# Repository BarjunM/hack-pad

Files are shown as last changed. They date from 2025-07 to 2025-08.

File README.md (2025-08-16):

# The DM’s Grimoire

The **DM’s Grimoire** is a D&D **macropad** built for Dungeon Masters to control their campaigns. With 9 mechanical keys, an OLED display, RGB lighting, and a custom spellbook‑style enclosure, this device becomes a physical “grimoire” of power for any tabletop roleplaying game.

---

## Why I Made This

As a long‑time Dungeon enjoyer and the permanent dungeon master (no thanks to my friends), I wanted something that was extremely functional — I wanted it to feel like an artifact from the game world itself. Instead of clicking around with a mouse, now I press a button and summon a thunderstorm… or a dragon roar.

---

## Project Photos

### Front View  
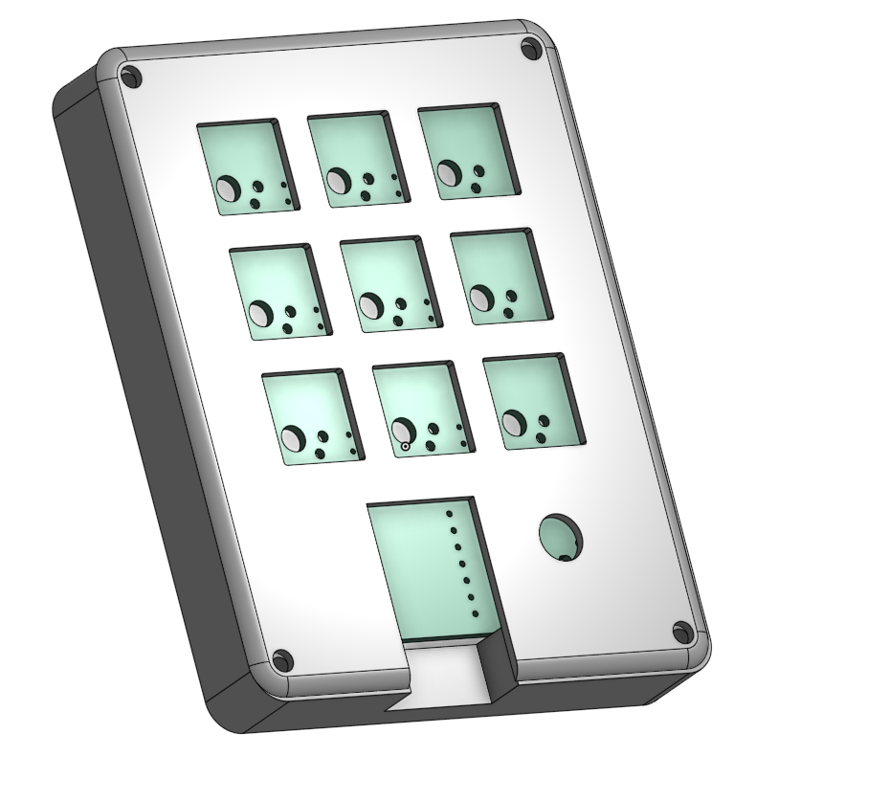
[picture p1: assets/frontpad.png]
Front of macropad


### Back View  
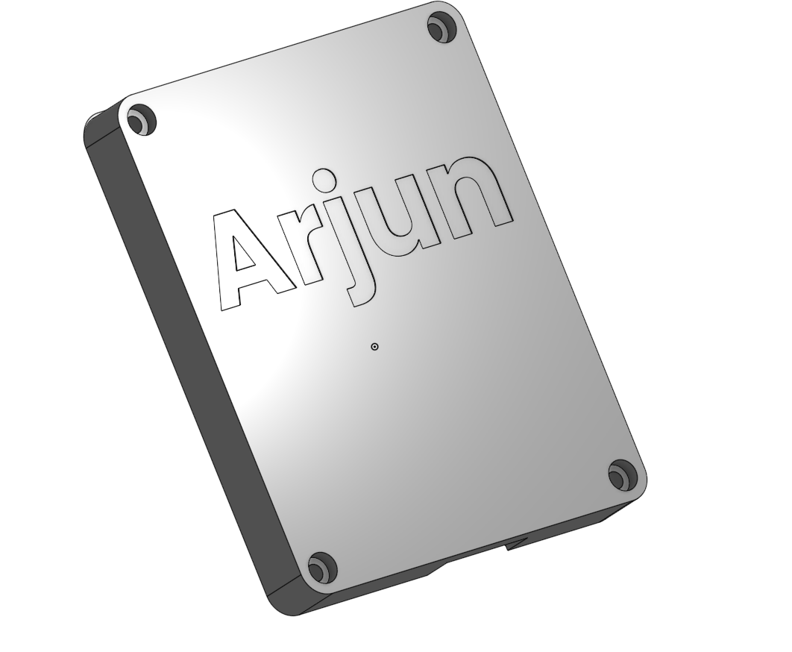
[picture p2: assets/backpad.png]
Back of macropad


---

## Key Orientation Screenshot

The 3D‑printed case was modeled in Onshape for a 3x3 matrix.

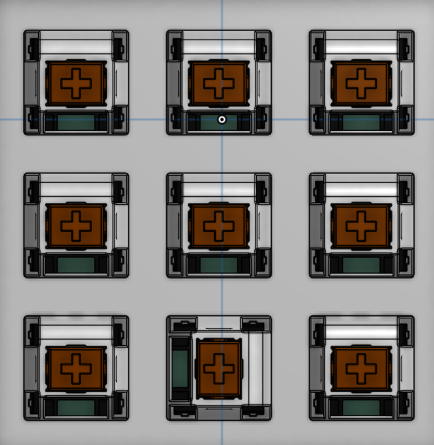
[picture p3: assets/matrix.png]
3D model render


---

## Wiring Diagram / Schematic

Here’s the schematic for all switches, OLED, and RGB integration:

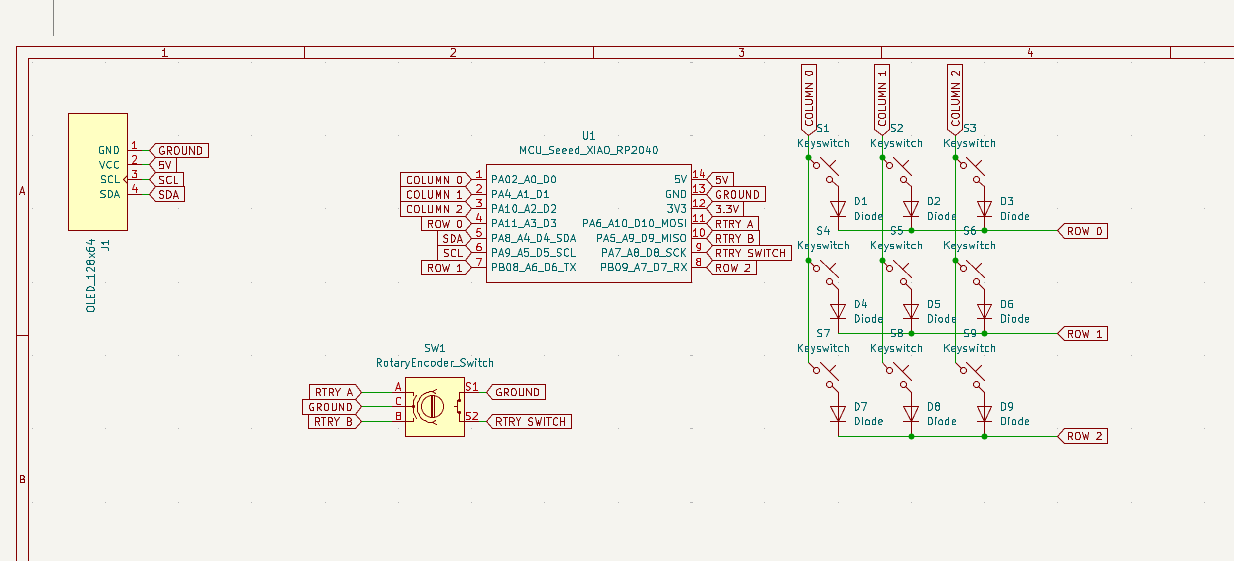
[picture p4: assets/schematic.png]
Schematic


---

## PCB Screenshot

Designed using KiCad and printed through Hack Club’s parts inventory.

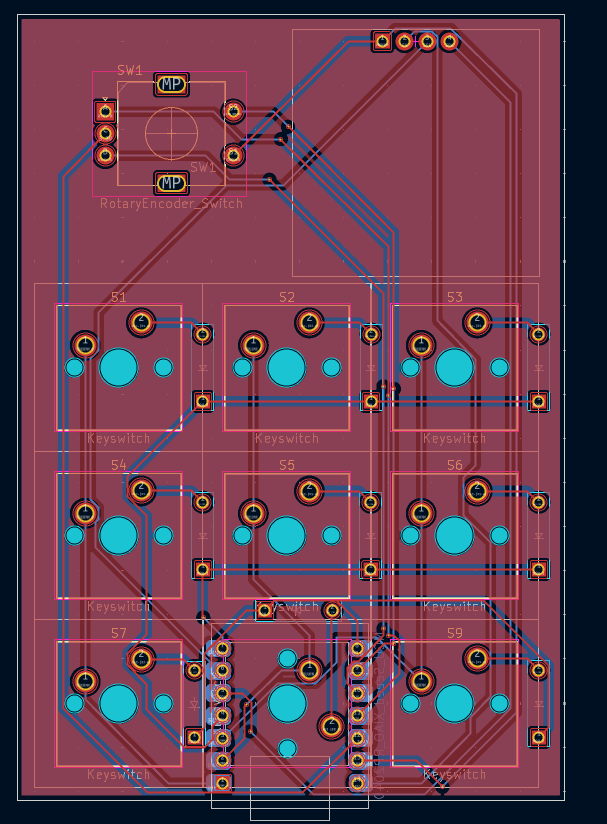
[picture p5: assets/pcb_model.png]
PCB design


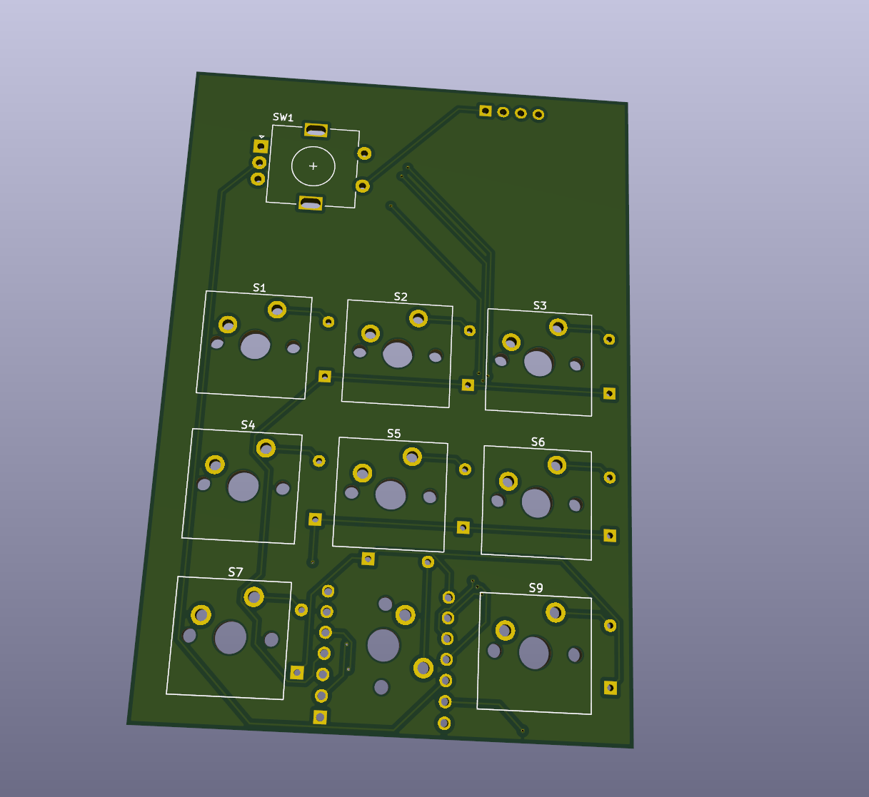
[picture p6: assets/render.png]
PCB render


---

## Assembly & Build Photos

Soldering, population, and final enclosure fit.

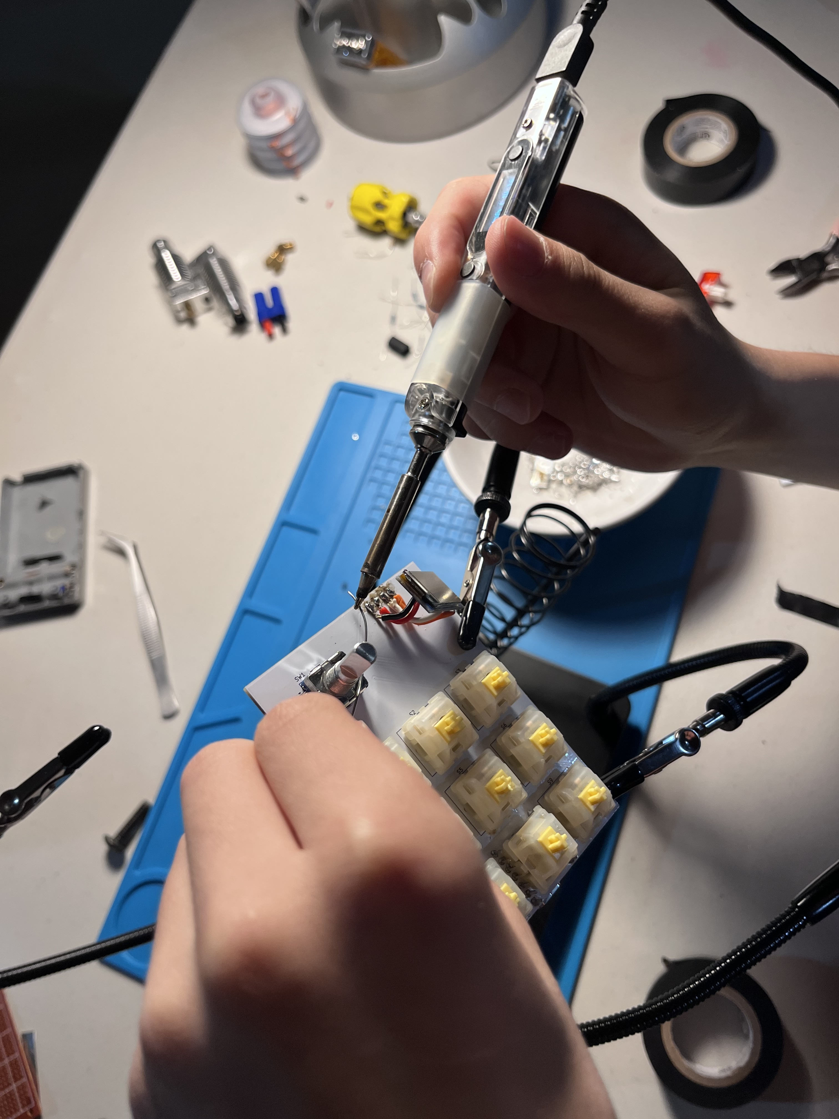
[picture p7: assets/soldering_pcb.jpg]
Soldering session

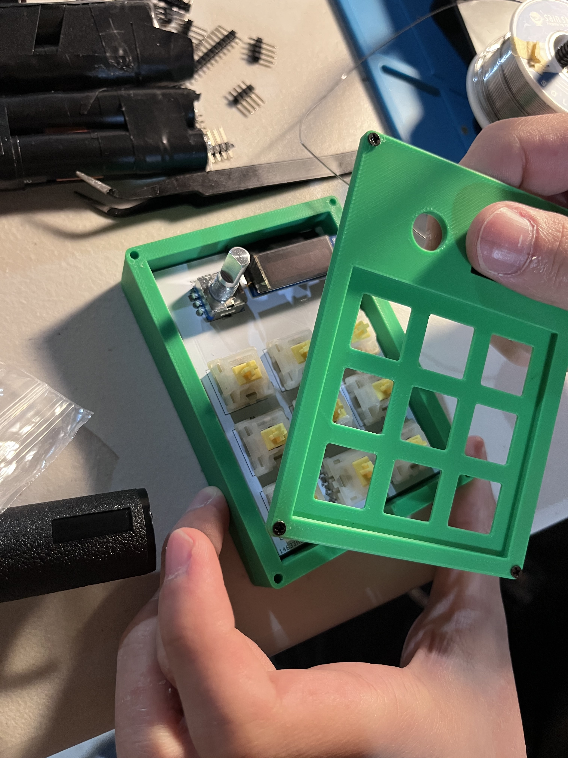
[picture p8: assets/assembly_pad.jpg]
Populated PCB

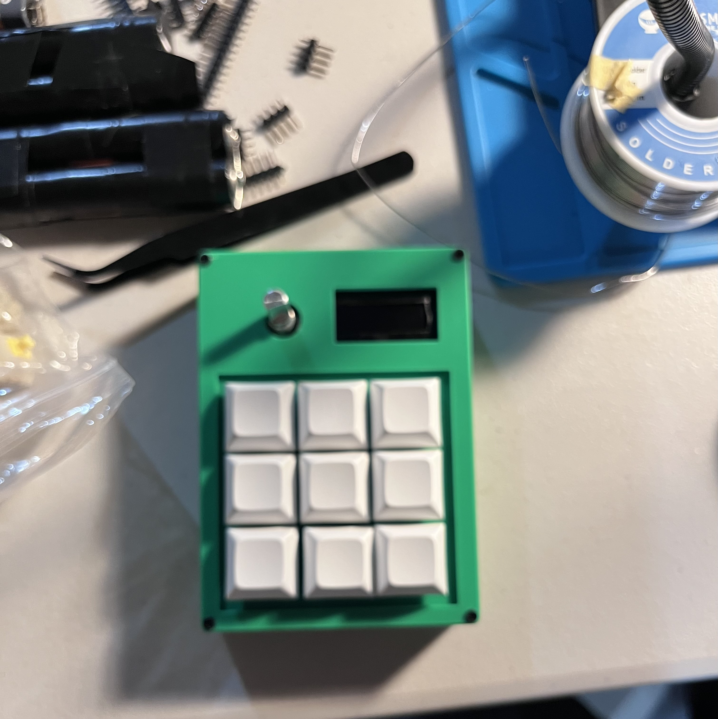
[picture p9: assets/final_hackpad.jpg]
Final assembly in case


---

## BOM
9x Cherry MX Switches
9x Blank DSA Keycaps
4x M3x5x4 Heatset inserts
4x M3x16mm SHCS Bolts
1x 0.91 inch OLED displays (Max 1x)
1x EC11 Rotary Encoder
1x XIAO RP2040
1x Case (2 printed parts)
1x Custom PCB

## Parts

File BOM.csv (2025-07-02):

Item | Quantity | Notes
Cherry MX Switches | 9
Blank DSA Keycaps | 9
M3x5x4 Heatset Inserts | 4
M3x16mm SHCS Bolts | 4
0.91 inch OLED Display | 1 | Max 1x
EC11 Rotary Encoder | 1
XIAO RP2040 | 1
Case (3D Printed Parts) | 1 | 2 printed parts
Custom PCB | 1

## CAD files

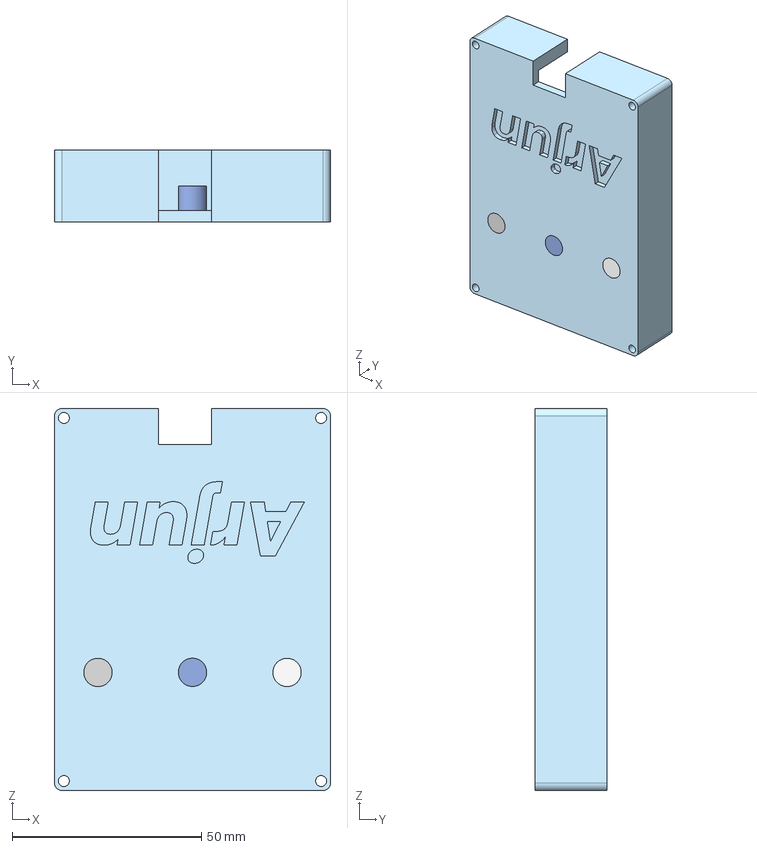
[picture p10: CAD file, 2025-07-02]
PRODUCTIOn/D&DPad - Case Base.step
73.0 x 19.0 x 101.0 mm

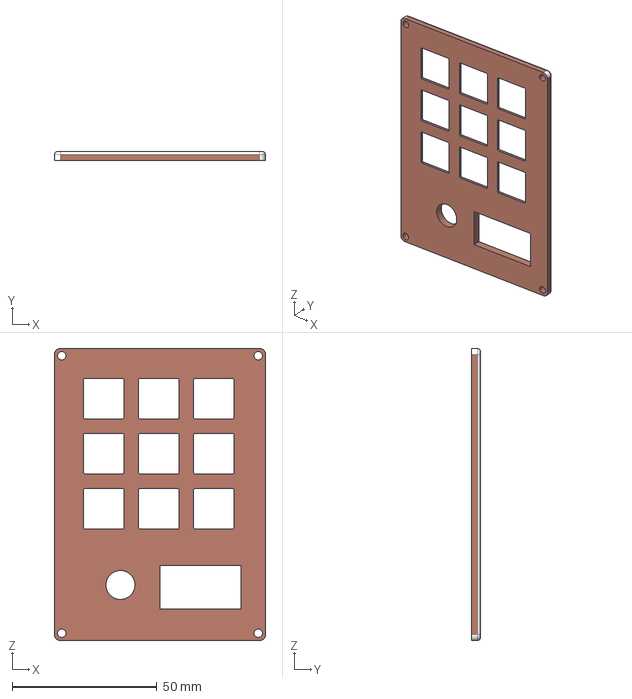
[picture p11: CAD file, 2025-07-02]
PRODUCTIOn/D&DPad - Top Plate.step
73.0 x 3.00 x 101.0 mm

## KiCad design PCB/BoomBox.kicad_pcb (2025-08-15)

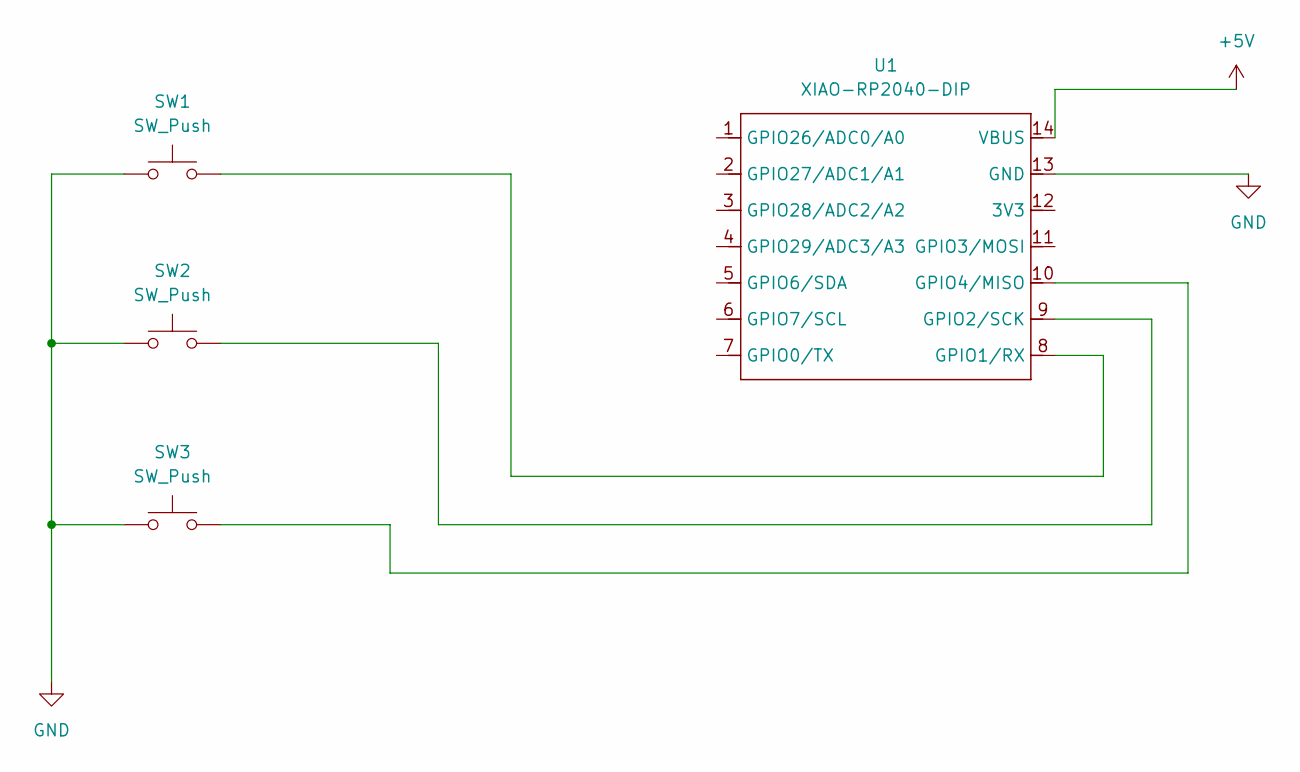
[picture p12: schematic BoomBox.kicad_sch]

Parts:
SW1, SW2, SW3: SW_Push; SW_Cherry_MX_1.00u_PCB
U1: XIAO-RP2040-DIP

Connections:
+5V: U1.14 (VBUS)
GND: SW1.1, SW2.1, SW3.1, U1.13 (GND)
unnamed: SW1.2, U1.8 (GPIO1/RX)
unnamed: SW2.2, U1.9 (GPIO2/SCK)
unnamed: SW3.2, U1.10 (GPIO4/MISO)

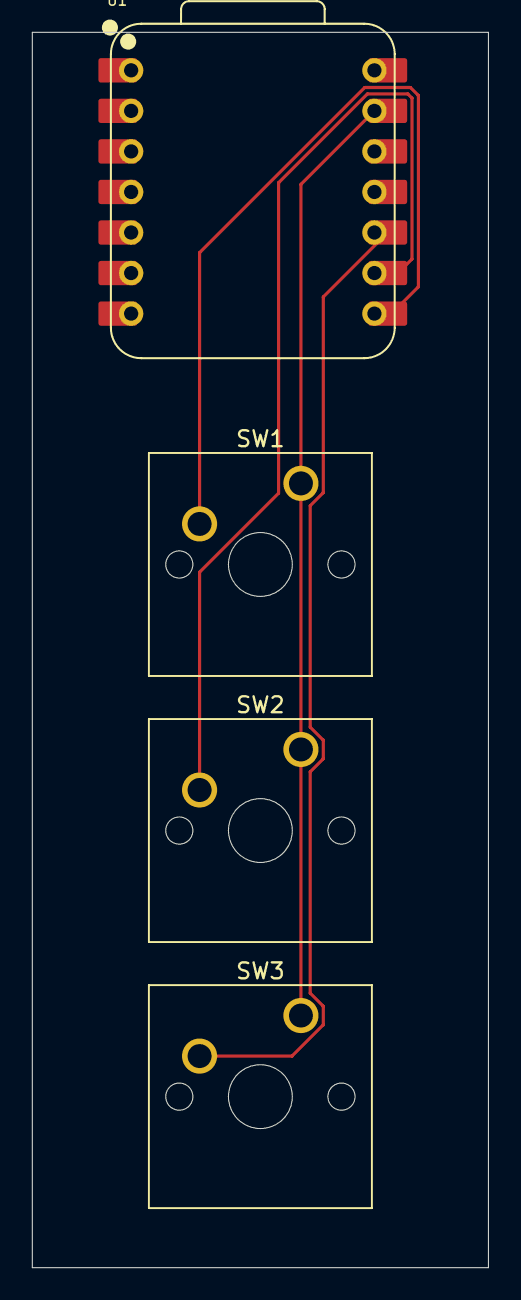
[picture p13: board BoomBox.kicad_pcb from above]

Board: 2 copper layers, 28.6 x 77.4 mm, 4 parts (0 on the bottom side), 4 nets.

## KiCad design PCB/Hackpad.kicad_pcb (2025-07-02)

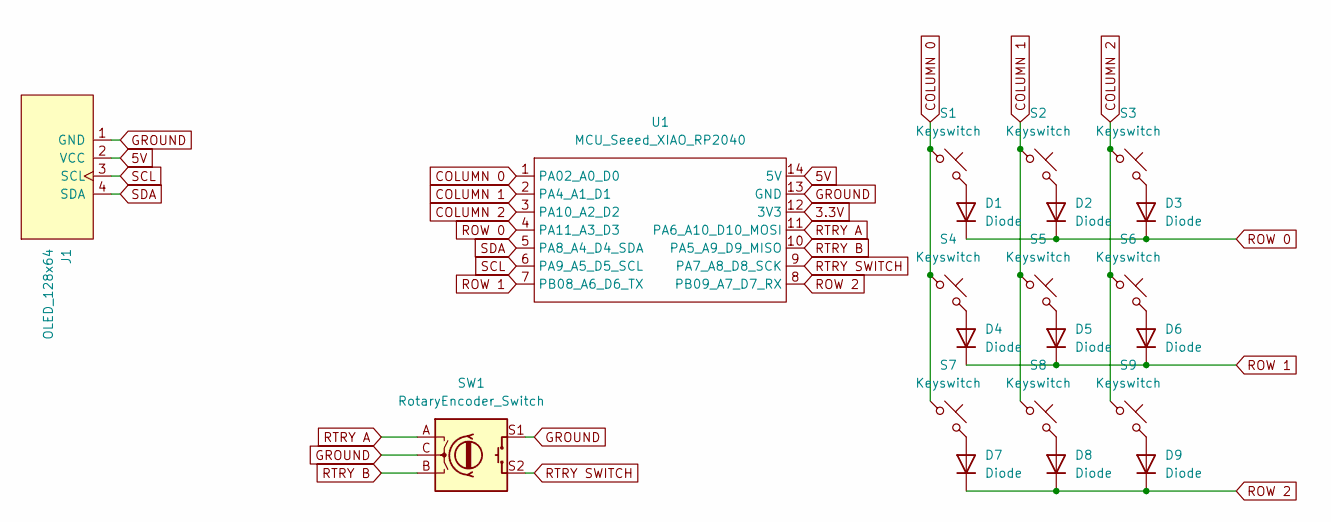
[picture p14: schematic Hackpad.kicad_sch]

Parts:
D1, D2, D3, D4, D5, D6, D7, D8, D9: Diode; Diode_DO-35
J1: OLED_128x64
S1, S2, S3, S4, S5, S6, S7, S8, S9: Keyswitch; MX_PCB_1.00u
SW1: RotaryEncoder_Switch; RotaryEncoder_Alps_EC11E-Switch_Vertical_H20mm
U1: MCU_Seeed_XIAO_RP2040; Seeed_XIAO_RP2040

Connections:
3.3V: U1.12 (3V3)
5V: J1.2 (VCC), U1.14 (5V)
COLUMN 0: S1.1, S4.1, S7.1, U1.1 (PA02_A0_D0)
COLUMN 1: S2.1, S5.1, S8.1, U1.2 (PA4_A1_D1)
COLUMN 2: S3.1, S6.1, S9.1, U1.3 (PA10_A2_D2)
GROUND: J1.1 (GND), SW1.C, SW1.S1, U1.13 (GND)
unnamed: D1.2 (A), S1.2
unnamed: D2.2 (A), S2.2
unnamed: D3.2 (A), S3.2
unnamed: D4.2 (A), S4.2
unnamed: D5.2 (A), S5.2
unnamed: D6.2 (A), S6.2
unnamed: D7.2 (A), S7.2
unnamed: D8.2 (A), S8.2
unnamed: D9.2 (A), S9.2
ROW 0: D1.1 (K), D2.1 (K), D3.1 (K), U1.4 (PA11_A3_D3)
ROW 1: D4.1 (K), D5.1 (K), D6.1 (K), U1.7 (PB08_A6_D6_TX)
ROW 2: D7.1 (K), D8.1 (K), D9.1 (K), U1.8 (PB09_A7_D7_RX)
RTRY A: SW1.A, U1.11 (PA6_A10_D10_MOSI)
RTRY B: SW1.B, U1.10 (PA5_A9_D9_MISO)
RTRY SWITCH: SW1.S2, U1.9 (PA7_A8_D8_SCK)
SCL: J1.3 (SCL), U1.6 (PA9_A5_D5_SCL)
SDA: J1.4 (SDA), U1.5 (PA8_A4_D4_SDA)

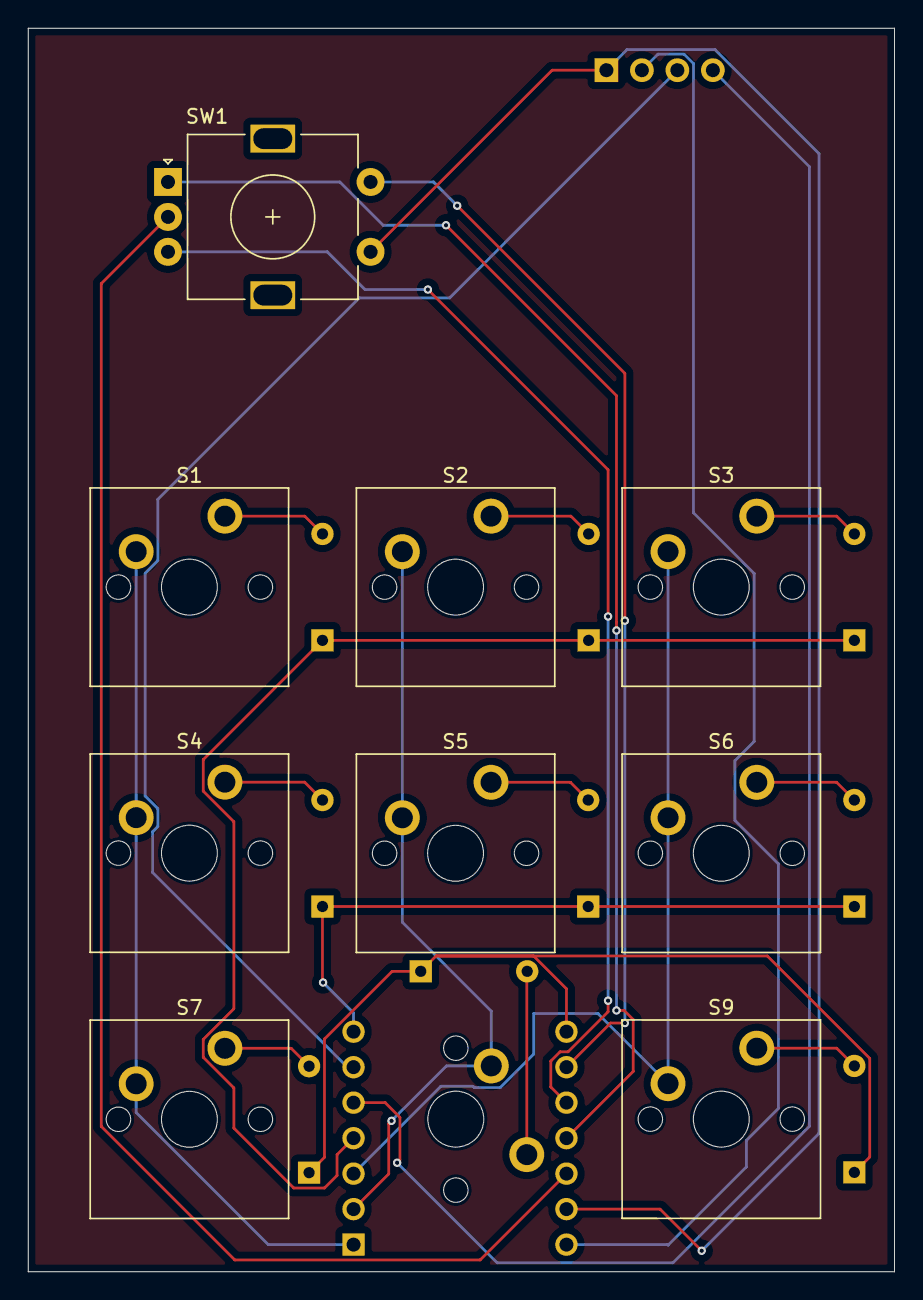
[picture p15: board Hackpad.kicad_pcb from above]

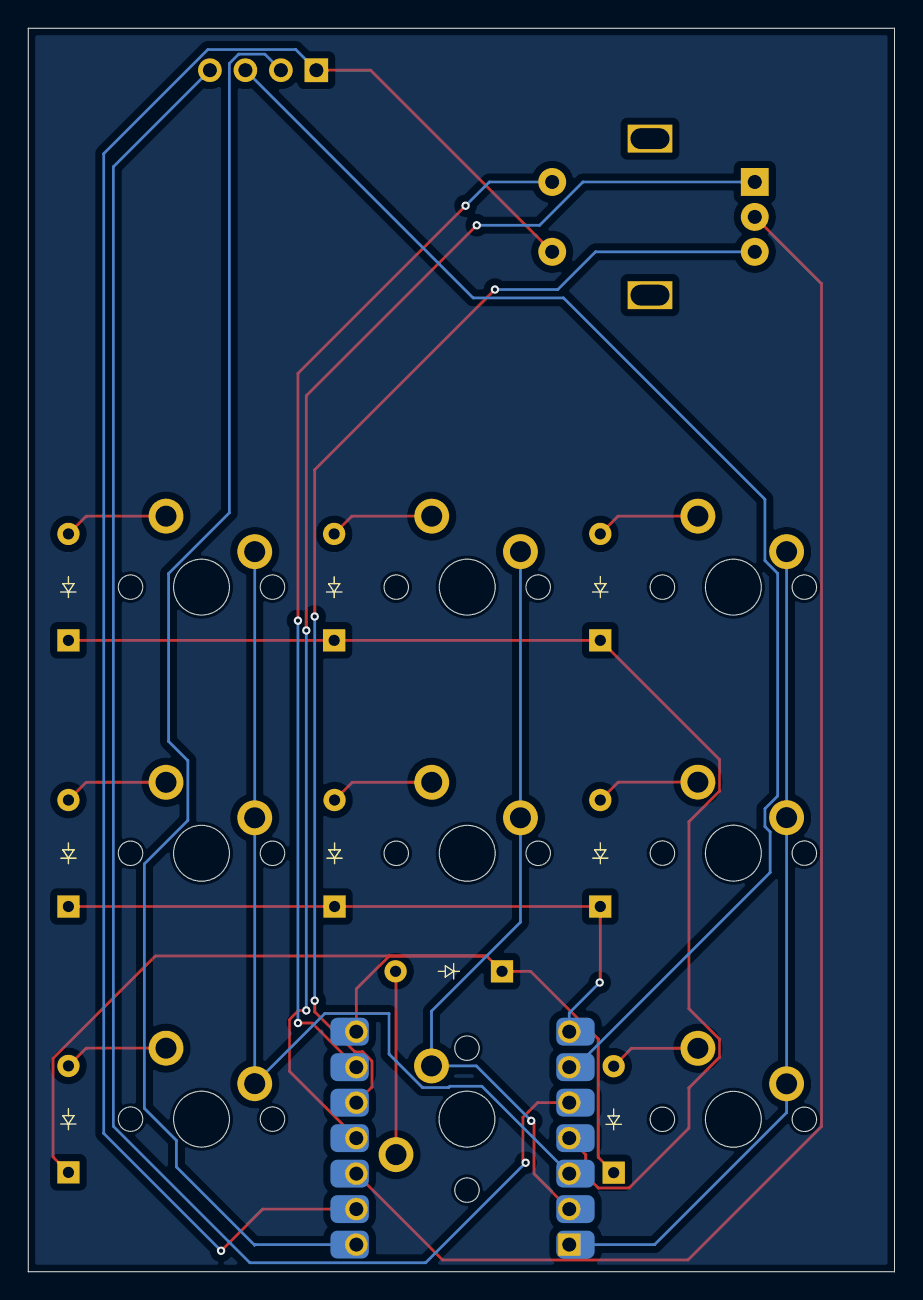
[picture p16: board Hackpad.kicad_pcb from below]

Board: 2 copper layers, 62.0 x 89.0 mm, 21 parts (10 on the bottom side), 22 nets.

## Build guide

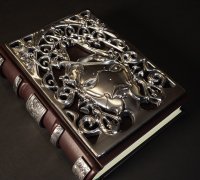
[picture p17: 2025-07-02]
assets/4144333_3d-file-grimoire-weiss-3d-printable-model-to-download-.jpg

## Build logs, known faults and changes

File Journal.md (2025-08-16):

---
title: "The DM’s Grimoire"
author: "Arjun Gupta"
description: "A fantasy‑themed macropad for Dungeon Masters to control sound, story, and combat  at the table."
created_at: "2025-06-26"
---

**Total time spent: 14h - 14.5h**

---

# June 26: Planning the Macropad

I sketched out my vision for the DM’s Grimoire today—9 spell‑like keys RGB mood lights, and a Pi Zero 2 W brain. Brainstormed feature list and started rough layout sketches. Also watched a bunch of tutorials on how to do this. 

initial sketch

**Total time spent: 2h**

---

# June 28: CAD Top Plate Prototype

In Onshape, I built the top plate: a 3×3 switch grid with cutout. Figured out switch spacing and screw hole placement. Struggled with making the screw hole stuff.

Config

**Total time spent: 1.5h**

---

# June 29: Engraving + Size

Fixed sizing of CAD, Adjusted the mount to be perfectly flush with the case surface.
Back of pad

**Total time spent: 1h**

---

# June 30: PCB Schematic & Layout

Created schematic in KiCad: 9‑switch thing, data line for WS2812. Laid out PCB footprint and aligned header pins. Realized I messed up the routing completly. learned how to route thanks to youtube, exported properly 

Schematic

PCB screenshot

PCB render

**Total time spent: 2.5h**

---

# July 1: Repo Setup & Documentation Prep

Pushed to github, Exported front/back pad renders and schematic. Waiting on parts, in the meantime planning how to code the firmware to intergrate with my D&D elements. Did research on communication protocols over bluetooth to control various elements (sound effects, lighting change, etc). Future steps, add in dungeon elements to the case. 

Front of pad

Back of pad

---

# August 1: Kit Arrival (Waiting on PCB)

Hackpad parts kit finally showed up today including the switches, OLED, rotary encoder, headers, basically everything except the actual PCB. Laid the components out, dry‑fitted a few switches into the printed plate just to feel the clicky satisfaction and verified the OLED clearance against the case model. Mostly a logistics day; resisted the urge to start soldering onto a proto board so I don't create extra work.

*No dedicated build time logged (inspection only).* 

---

# August 3: PCB Delivery + Case Print & Test Fit

PCB landed two days after the rest of the kit. Immediately sliced the case parts and printed the enclosure to confirm tolerances. Did a gentle test fit: PCB lined up with standoffs, switch plate seated cleanly, and the encoder shaft cleared the opening exactly as planned. Huge relief that the footprint exports and spacing decisions were solid.

*Time not formally tracked (fit/print cycle + inspection).* 

---

# August 4: Full Solder Session

Big build push today. Soldered all 9 switches, the Seeed XIAO RP2040, the OLED header, and the rotary encoder. Midway through I snapped a pin on one switch while re‑aligning, swapped it out with a spare, no harm done. Continuity‑checked the data line and power rails; everything looked clean under magnification. Board is now electrically alive.

Soldering session
PCB

**Total time spent: 2h**

---

# August 5: Firmware Pivot & Feature Mapping

Started firmware with Arduino tooling, but hit the wall when I wanted Python + KMK flexibility. Switched over to CircuitPython; reflashed the XIAO and rebuilt the layout logic. Mapped the 9 keys into thematic groups: 3 for RGB ambient modes, 3 bound to auto dice rolls (different dice faces), and 3 triggering sound effect hooks. Rotary encoder + OLED groundwork laid for future status display (e.g., active lighting mode / last roll). Core event loop now stable.

**Total time spent: 3h**

---

# August 7: Final Assembly & Validation

Did an integrated test pass before sealing it up. All switches firing, RGB routines cycling, dice roll functions returning correct ranges, and sound effect triggers dispatching. Mounted PCB into the printed case, fastened screws, gently torque‑checked so I don't warp the board. Quick re‑test after enclosure closure — solid. Ready for real session use.

Final assembly in case

Demo video: https://youtube.com/shorts/aW9sag3_JPg
Demo Link: https://www.reddit.com/r/ArjunsWorld/comments/1mqmux4/hackpad/

**Total time spent: 0.5h**

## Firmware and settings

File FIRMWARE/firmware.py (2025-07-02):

import board
import busio
from kmk.kmk_keyboard import KMKKeyboard
from kmk.keys import KC
from kmk.scanners import DiodeOrientation
from kmk.modules.encoder import EncoderHandler
from kmk.extensions.media_keys import MediaKeys
from kmk.handlers.sequences import simple_key_sequence
from kmk.modules.layers import Layers
from kmk.extensions.display import Display, SSD1306, TextEntry, ImageEntry

i2c_bus = busio.I2C(board.GP21, board.GP20)
display_driver = SSD1306(
    i2c=i2c_bus,
    # Optional device_addres argument. Default is 0x3C.
    # device_address=0x3C,
)

display = Display(
    display=display_driver,
    entries=[
        TextEntry(text='DM Pad:', x=0, y=16, y_anchor='T'),
        TextEntry(text='AMBIENCE', x=0, y=32, y_anchor='B', layer=0),
        TextEntry(text='COMBAT', x=0, y=32, y_anchor='B', layer=1),
        TextEntry(text='UTILITY', x=0, y=32, y_anchor='B', layer=2),
    ],
    height=64,
    dim_time=10,
    dim_target=0.2,
    off_time=1200,
    brightness=1,
)

keyboard = KMKKeyboard()
layers = Layers()
encoder_handler = EncoderHandler()
keyboard.modules.append(layers)
keyboard.modules.append(encoder_handler)
keyboard.extensions.append(MediaKeys())
keyboard.extensions.append(display)

# Define matrix pins based on the schematic, using GP pins
keyboard.col_pins = (board.GP0, board.GP1, board.GP2)  # COLUMN_1, COLUMN_2, COLUMN_3
keyboard.row_pins = (board.GP3, board.GP4, board.GP5)  # ROW_A, ROW_B, ROW_C
keyboard.diode_orientation = DiodeOrientation.COL2ROW

# D&D Dungeon Master Macros

# Ambience and Lighting Controls
TAVERN_AMBIENCE = simple_key_sequence((KC.LGUI(KC.R), KC.MACRO_SLEEP_MS(100), KC.COPY("https://mynoise.net/NoiseMachines/tavern.php"), KC.ENTER))
FOREST_AMBIENCE = simple_key_sequence((KC.LGUI(KC.R), KC.MACRO_SLEEP_MS(100), KC.COPY("https://mynoise.net/NoiseMachines/darkWorld.php"), KC.ENTER))
DUNGEON_AMBIENCE = simple_key_sequence((KC.LGUI(KC.R), KC.MACRO_SLEEP_MS(100), KC.COPY("https://mynoise.net/NoiseMachines/caveNoiseGenerator.php"), KC.ENTER))

# Combat Sound Effects
SWORD_CLASH = simple_key_sequence((KC.LGUI(KC.R), KC.MACRO_SLEEP_MS(100), KC.COPY("freesound.org/people/Hybrid_V/sounds/321215/"), KC.ENTER))
SPELL_CAST = simple_key_sequence((KC.LGUI(KC.R), KC.MACRO_SLEEP_MS(100), KC.COPY("freesound.org/people/qubodup/sounds/219568/"), KC.ENTER))
DRAGON_ROAR = simple_key_sequence((KC.LGUI(KC.R), KC.MACRO_SLEEP_MS(100), KC.COPY("freesound.org/people/Marianne_Gagnon/sounds/131961/"), KC.ENTER))

# Quick Utility Macros
ROLL_D20 = simple_key_sequence((KC.COPY("/roll 1d20"), KC.ENTER))
INITIATIVE_TRACKER = simple_key_sequence((KC.LGUI(KC.R), KC.MACRO_SLEEP_MS(100), KC.COPY("https://www.improved-initiative.com/"), KC.ENTER))
DND_BEYOND = simple_key_sequence((KC.LGUI(KC.R), KC.MACRO_SLEEP_MS(100), KC.COPY("https://www.dndbeyond.com/"), KC.ENTER))

# Lighting Controls (assuming smart lights or OBS scenes)
DIM_LIGHTS = simple_key_sequence((KC.LALT(KC.F1)))  # OBS Scene hotkey
BRIGHT_LIGHTS = simple_key_sequence((KC.LALT(KC.F2)))  # OBS Scene hotkey
RED_COMBAT_LIGHTS = simple_key_sequence((KC.LALT(KC.F3)))  # OBS Scene hotkey

# Define multi-layer keymap for different DM functions
keyboard.keymap = [
    # Layer 0: Ambience & Environment
    [
        TAVERN_AMBIENCE,    FOREST_AMBIENCE,     DUNGEON_AMBIENCE,
        DIM_LIGHTS,         BRIGHT_LIGHTS,       KC.MO(1),  # Hold for Layer 1
        KC.MUTE,            KC.VOLD,             KC.TO(2)   # To Layer 2
    ],
    # Layer 1: Combat & Effects
    [
        SWORD_CLASH,        SPELL_CAST,          DRAGON_ROAR,
        RED_COMBAT_LIGHTS,  ROLL_D20,            KC.TRNS,   # Transparent (back to base)
        KC.MEDIA_PLAY_PAUSE, KC.MEDIA_PREV_TRACK, KC.TO(0)   # Back to Layer 0
    ],
    # Layer 2: Utilities & Tools
    [
        INITIATIVE_TRACKER, DND_BEYOND,          KC.LGUI(KC.L),  # Lock screen
        KC.LCTL(KC.T),      KC.LCTL(KC.W),       KC.LCTL(KC.LSHIFT(KC.T)),  # Browser tabs
        KC.LALT(KC.TAB),    KC.LCTL(KC.C),       KC.TO(0)   # Back to Layer 0
    ]
]

# Configure encoder for volume/music control
encoder_handler.pins = ((board.GP6, board.GP7, board.GP8),)  # ENCA, ENCB, ENC_SWITCH
# Encoder map - volume control and mute
encoder_handler.map = [(
    (KC.VOLU, KC.VOLD),  # Rotate for volume
    KC.MUTE              # Press to mute
)]

if __name__ == '__main__':
    keyboard.go()

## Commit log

2025-07-01 updated pcb + fixed cad
    [Grove - Vision AI Module V2.kicad_pcb, Grove - Vision AI Module V2.kicad_sch, Grove_Vision_AI_V2_BOM.xlsx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]
2025-07-02 Overwrite main branch with local files
    [D&DPad - Case Base.step, D&DPad - Top Plate.step, Grove - Vision AI Module V2.kicad_pcb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]
2025-07-02 add/fix prod stuff
    [BOM.csv]
2025-07-02 Updated Image Files v3
    [Hackpad.kicad_pcb, Hackpad.kicad_sch]
2025-08-15 just updated
    [BoomBox.kicad_pcb, BoomBox.kicad_sch]
